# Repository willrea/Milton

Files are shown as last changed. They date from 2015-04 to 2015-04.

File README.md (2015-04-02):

# Milton

LPC1768-based platform for high altitude balloons.

###Hardware

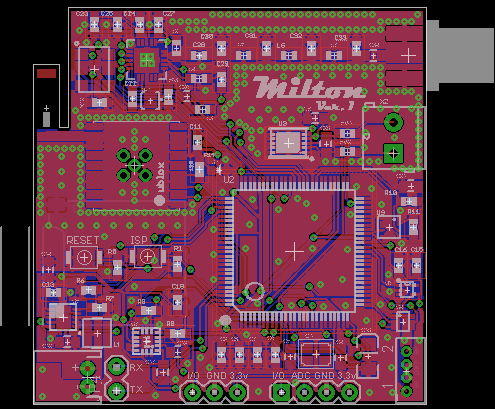
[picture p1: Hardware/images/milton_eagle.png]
Eagle


Includes:
* ublox MAX7 GPS
* Bosch BME280 Pressure/Humidity/Temperature Sensor
* Si4464 RF IC to transmit position via APRS
* Capability to trigger 2 Canon cameras loaded with CHDK
* MMA8452Q Accelerometer
* Supports a thermocouple for exterior temperature reading via a OneWire MAX31850

###Software###

*Overview of software functions*
* Beacon position and temps over APRS in a configurable amount of time
 * Add support for SI4464 RF IC
* Log raw NMEA strings to file on SD card
* Log sensor info with date/time and gps position on SD card, maybe in same file as NMEA strings? Would have to be 
compatible with GPSBabel or similar program.
* Trigger up to 2 cameras on set intervals
* Detect apogee via accelerometer triggering interrupt. Then trigger cameras and log gps at time of apogee

Hardware is licensed under a <a rel="license" href="http://creativecommons.org/licenses/by-sa/4.0/">Creative Commons Attribution-ShareAlike 4.0 International License</a>.

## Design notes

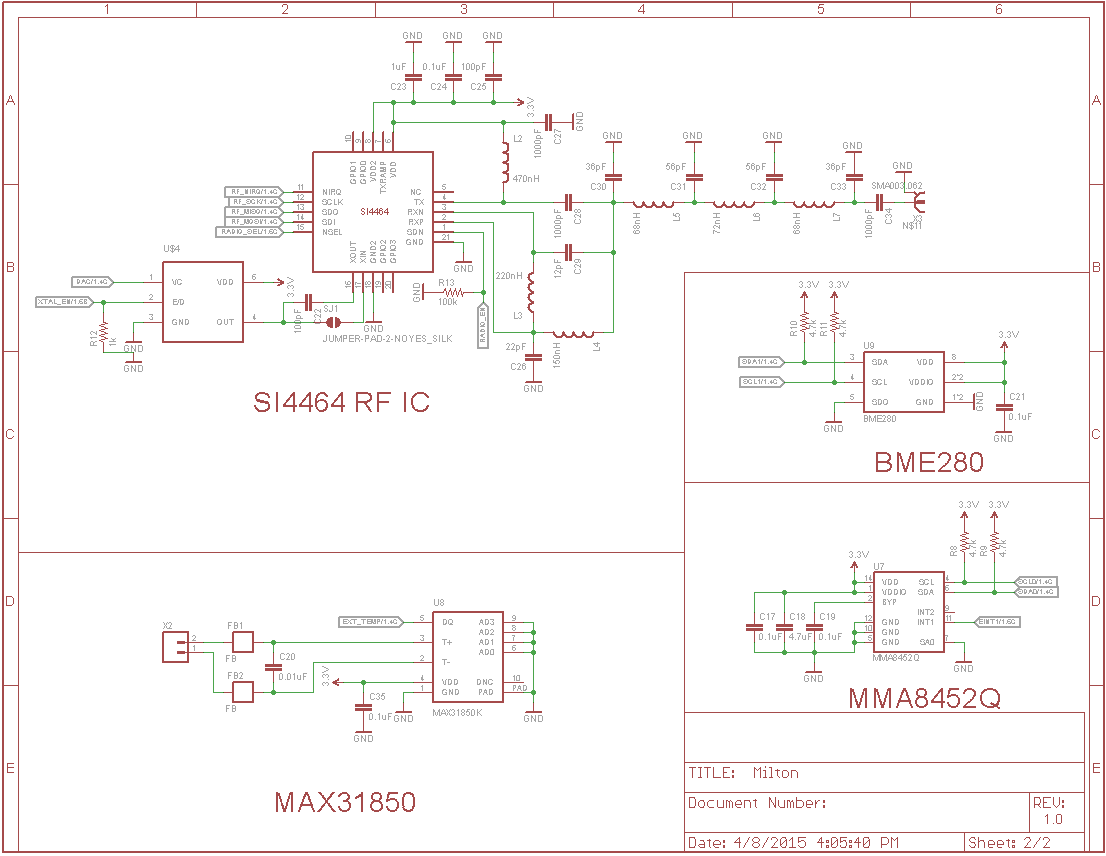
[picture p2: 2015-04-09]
Hardware/images/Schematic_P2.png

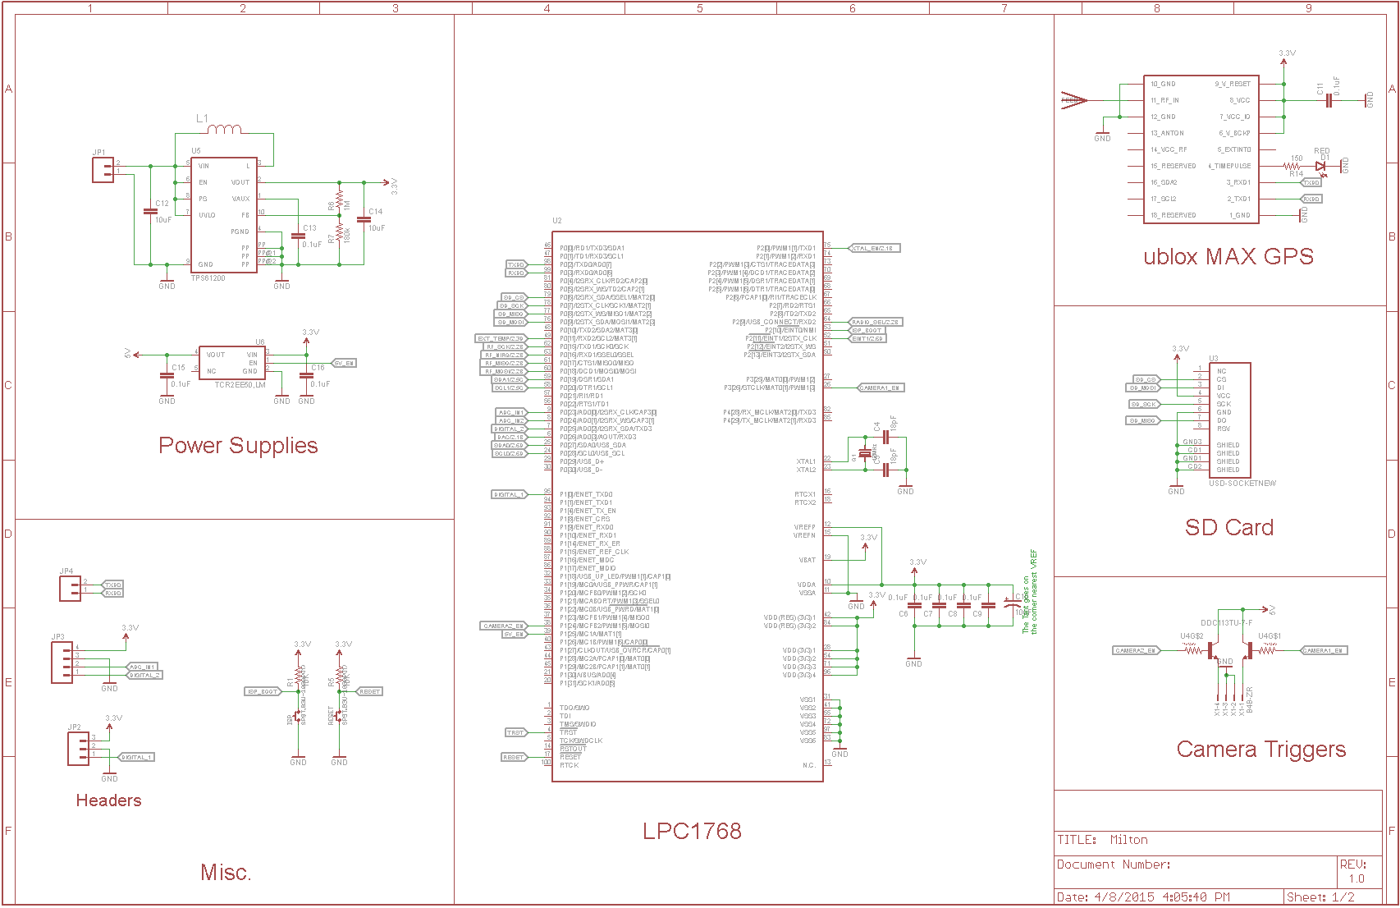
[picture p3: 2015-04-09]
Hardware/images/Schematic_P1.png

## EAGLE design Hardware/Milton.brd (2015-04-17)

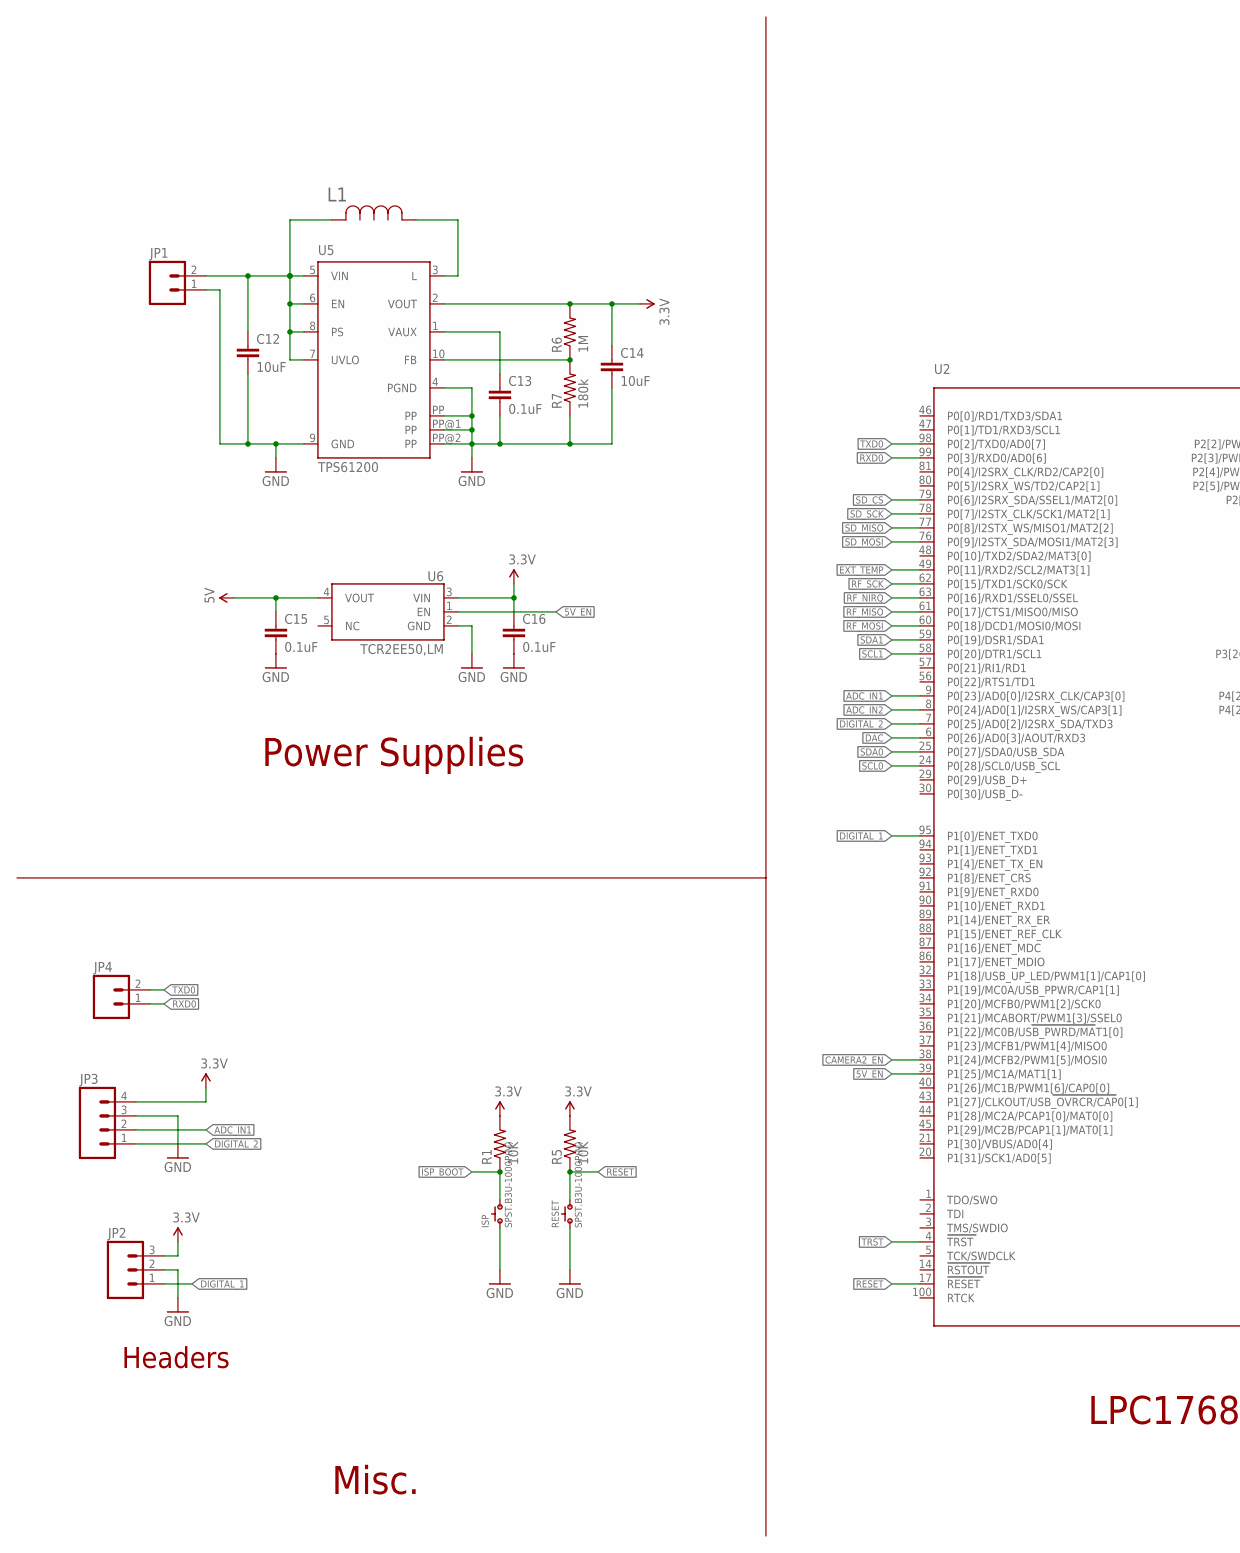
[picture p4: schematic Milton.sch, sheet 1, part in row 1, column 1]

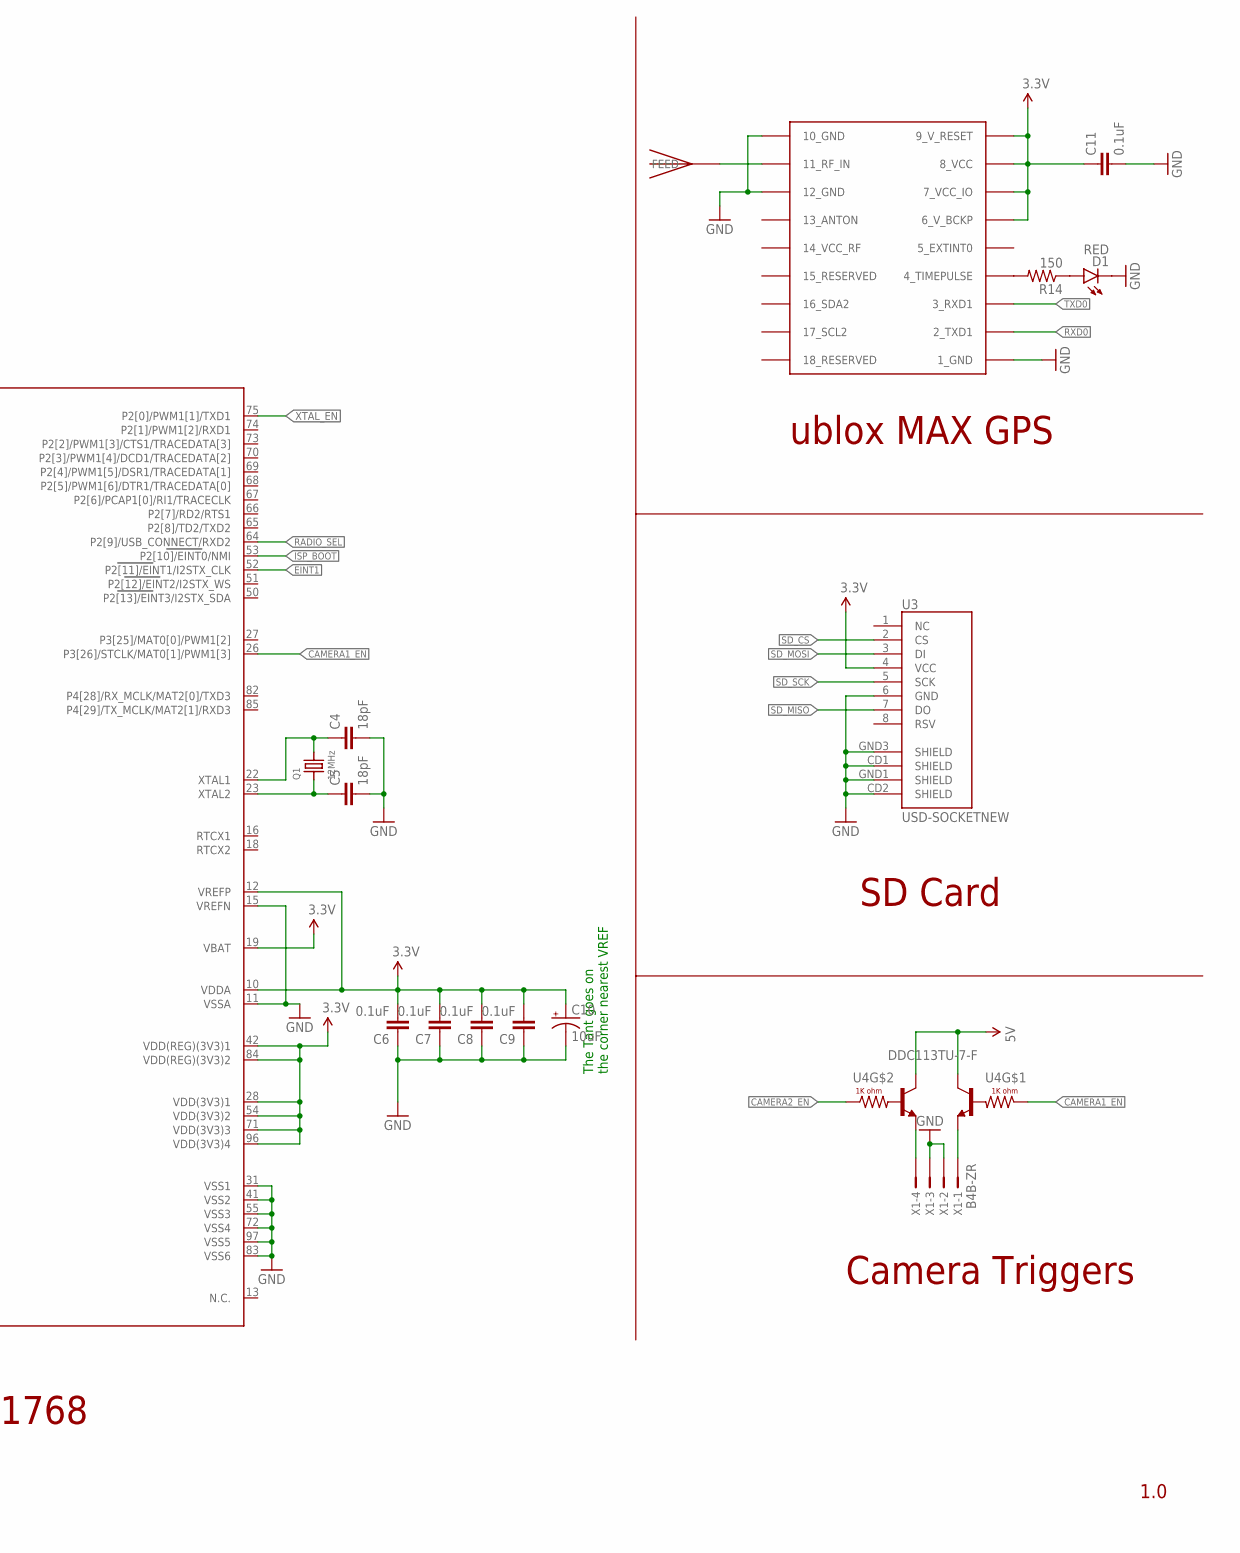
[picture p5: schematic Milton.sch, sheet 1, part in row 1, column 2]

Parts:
C4, C5: 18pF; 0805; MPN C0603C180K3GACTU
C6, C7, C8, C9, C11, C13, C15, C16: 0.1uF; 0603-CAP; MPN CL10B104KO8NNNC
C10: 10uF; EIA3216; MPN F931A106KAA
C12, C14: 10uF; 0805; MPN GRM21BR61C106KE15L
D1: RED; LED-0603; MPN LS L29K-G1J2-1-Z
ISP: SPST.B3U-1000P(M); B3U-1000P(M)
JP1: M02JST-PTH-2; JST-2-PTH; MPN S2B-PH-K-S(LF)(SN)
JP2: M03PTH; 1X03
JP3: M04PTH; 1X04
JP4: M02LOCK; 1X02_LOCK
L1: SRN3015-2R2M; IND_BOURNS_SRN3015; MPN SRN3015-4R7M
Q1: 12MHz; CRYSTAL_3.2X2.5; MPN 7V-12.000MAHE-T
R1, R5: 10K; 0603-RES; MPN ESR03EZPJ103
R6: 1M; 0603-RES; MPN MCT06030C1004FP500
R7: 180k; 0603-RES; MPN RC1608F184CS
R14: 150; 0603-RES; MPN ESR03EZPJ151
RESET: SPST.B3U-1000P(M); B3U-1000P(M)
U2: LPC1768; LQFP100; MPN LPC1768FBD100,551
U3: USD-SOCKETNEW; MICRO-SD-SOCKET-PP; MPN 101-00660-68-6
U4: DDC113TU-7-F; SC70−6; MPN DDC113TU-7-F
U5: TPS61200; S-PDSO-N10; MPN TPS61200DRCR
U6: TCR2EE50,LM; SOT50P160X60-5N
U$2: 1575AT43A40; JTI_ANTENNA-1575AT43A40; MPN 1575AT43A0040E
U$3: UBLOX_MAX; MPN MAX-7C-0
X1: B4B-ZR

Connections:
3.3V: C6.2, C7.2, C8.2, C9.2, C10.A (+), C11.1, C14.1, C16.1, JP2.3, JP3.4, R1.2, R5.2, R6.2, U2.10 (VDDA), U2.12 (VREFP), U2.19 (VBAT), U2.28 (VDD(3V3)1), U2.42 (VDD(REG)(3V3)1), U2.54 (VDD(3V3)2), U2.71 (VDD(3V3)3), U2.84 (VDD(REG)(3V3)2), U2.96 (VDD(3V3)4), U3.4 (VCC), U5.2 (VOUT), U6.3 (VIN), U$3.6_V_BCKP, U$3.7_VCC_IO, U$3.8_VCC, U$3.9_V_RESET; also elsewhere on the board
5V: C15.1, U4.3 (C), U4.6 (C), U6.4 (VOUT)
5V_EN: U2.39 (P1[25]/MC1A/MAT1[1]), U6.1 (EN)
ADC_IN1: JP3.2, U2.9 (P0[23]/AD0[0]/I2SRX_CLK/CAP3[0])
ADC_IN2: U2.8 (P0[24]/AD0[1]/I2SRX_WS/CAP3[1])
CAM1: U4.1 (E), X1.1
CAM2: U4.4 (E), X1.4
CAMERA1_EN: U2.26 (P3[26]/STCLK/MAT0[1]/PWM1[3]), U4.2 (B)
CAMERA2_EN: U2.38 (P1[24]/MCFB2/PWM1[5]/MOSI0), U4.5 (B)
DAC: U2.6 (P0[26]/AD0[3]/AOUT/RXD3); also elsewhere on the board
DIGITAL_1: JP2.1, U2.95 (P1[0]/ENET_TXD0)
DIGITAL_2: JP3.1, U2.7 (P0[25]/AD0[2]/I2SRX_SDA/TXD3)
EINT1: U2.52 (P2[11]/EINT1/I2STX_CLK); also elsewhere on the board
EXT_TEMP: U2.49 (P0[11]/RXD2/SCL2/MAT3[1]); also elsewhere on the board
GND: C4.2, C5.2, C6.1, C7.1, C8.1, C9.1, C10.C (-), C11.2, C12.2, C13.2, C14.2, C15.2, C16.2, D1.C, ISP.1, JP1.1, JP2.2, JP3.3, R7.1, RESET.1, U2.11 (VSSA), U2.15 (VREFN), U2.31 (VSS1), U2.41 (VSS2), U2.55 (VSS3), U2.72 (VSS4), U2.83 (VSS6), U2.97 (VSS5), U3.6 (GND), U3.CD1 (SHIELD), U3.CD2 (SHIELD), U3.GND1 (SHIELD), U3.GND3 (SHIELD), U5.4 (PGND), U5.9 (GND), U5.PP, U5.PP@1 (PP), U5.PP@2 (PP), U6.2 (GND), U$3.1_GND, U$3.10_GND, U$3.12_GND, X1.2, X1.3; also elsewhere on the board
IC6_RTC1: C4.1, Q1.2, U2.22 (XTAL1)
IC6_RTC2: C5.1, Q1.1, U2.23 (XTAL2)
ISP_BOOT: ISP.2, R1.1, U2.53 (P2[10]/EINT0/NMI)
unnamed: R6.1, R7.2, U5.10 (FB)
unnamed: U$2.FEED, U$3.11_RF_IN
unnamed: D1.A, R14.1
unnamed: L1.1, U5.3 (L)
unnamed: R14.2, U$3.4_TIMEPULSE
RADIO_SEL: U2.64 (P2[9]/USB_CONNECT/RXD2); also elsewhere on the board
RESET: R5.1, RESET.2, U2.17 (RESET)
RF_MISO: U2.61 (P0[17]/CTS1/MISO0/MISO); also elsewhere on the board
RF_MOSI: U2.60 (P0[18]/DCD1/MOSI0/MOSI); also elsewhere on the board
RF_NIRQ: U2.63 (P0[16]/RXD1/SSEL0/SSEL); also elsewhere on the board
RF_SCK: U2.62 (P0[15]/TXD1/SCK0/SCK); also elsewhere on the board
RXD0: JP4.1, U2.99 (P0[3]/RXD0/AD0[6]), U$3.2_TXD1
SCL0: U2.24 (P0[28]/SCL0/USB_SCL); also elsewhere on the board
SCL1: U2.58 (P0[20]/DTR1/SCL1); also elsewhere on the board
SDA0: U2.25 (P0[27]/SDA0/USB_SDA); also elsewhere on the board
SDA1: U2.59 (P0[19]/DSR1/SDA1); also elsewhere on the board
SD_CS: U2.79 (P0[6]/I2SRX_SDA/SSEL1/MAT2[0]), U3.2 (CS)
SD_MISO: U2.77 (P0[8]/I2STX_WS/MISO1/MAT2[2]), U3.7 (DO)
SD_MOSI: U2.76 (P0[9]/I2STX_SDA/MOSI1/MAT2[3]), U3.3 (DI)
SD_SCK: U2.78 (P0[7]/I2STX_CLK/SCK1/MAT2[1]), U3.5 (SCK)
TRST: U2.4 (TRST)
TXD0: JP4.2, U2.98 (P0[2]/TXD0/AD0[7]), U$3.3_RXD1
VAUX: C13.1, U5.1 (VAUX)
VIN: C12.1, JP1.2, L1.2, U5.5 (VIN), U5.6 (EN), U5.7 (UVLO), U5.8 (PS)
XTAL_EN: U2.75 (P2[0]/PWM1[1]/TXD1); also elsewhere on the board

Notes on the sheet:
The Tant goes on the corner nearest VREF
LPC1768
ublox MAX GPS
SD Card
Camera Triggers
Power Supplies
1.0
Headers
Misc.

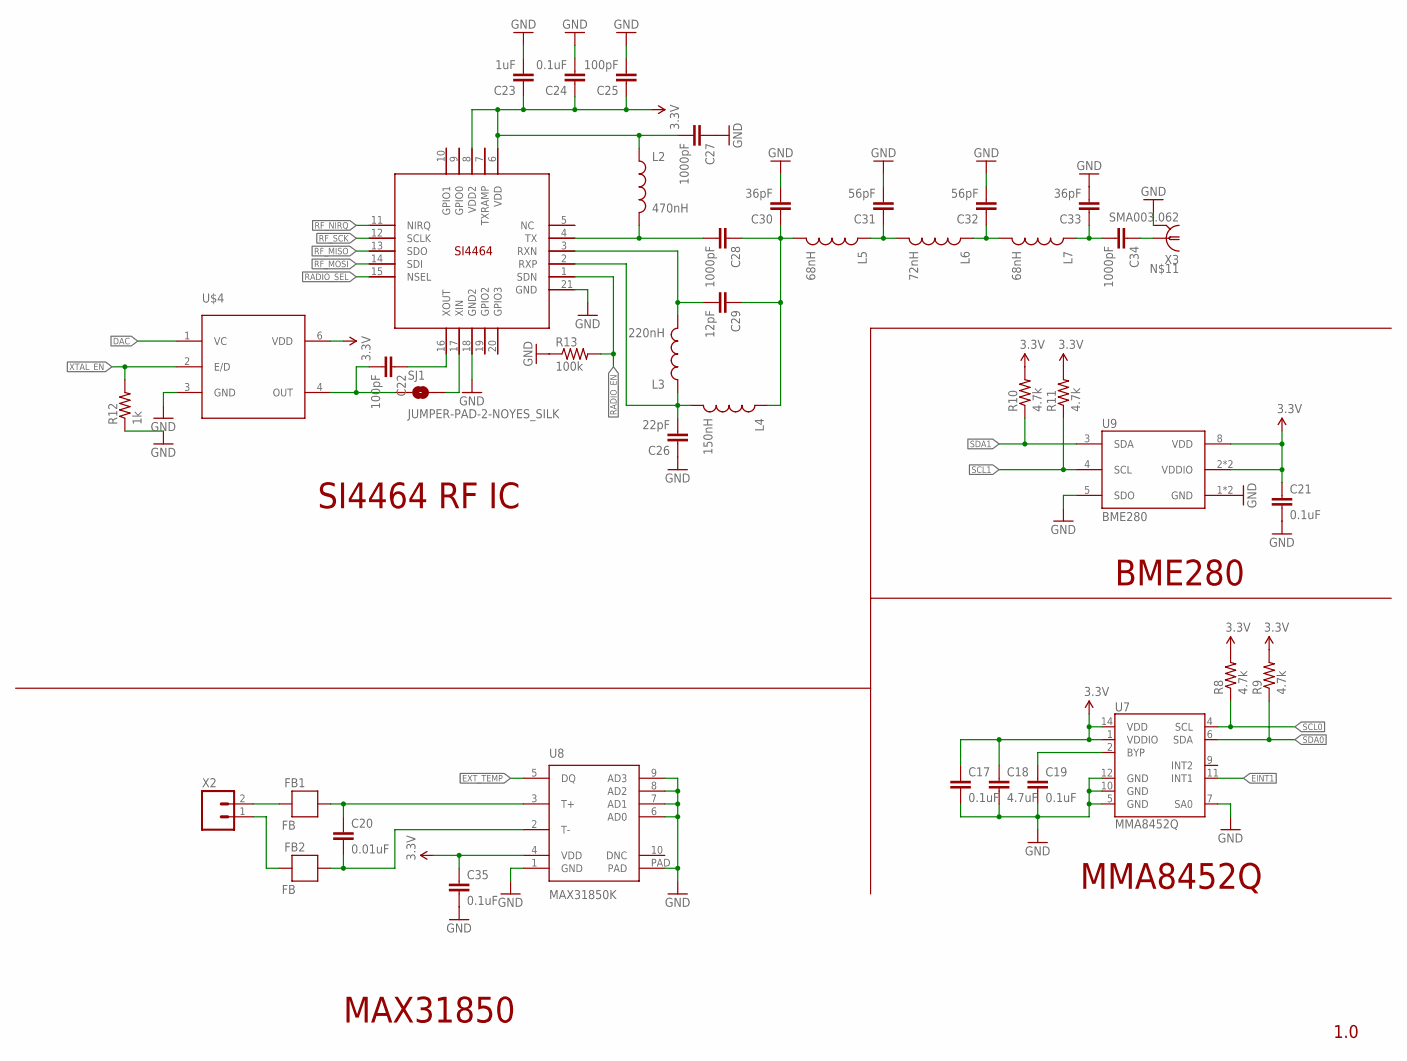
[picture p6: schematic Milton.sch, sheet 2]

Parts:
C17, C19, C21, C35: 0.1uF; 0805; MPN CL10B104KO8NNNC
C18: 4.7uF; 0603-CAP; MPN CC0603KRX5R6BB475
C20: 0.01uF; 0805; MPN C0603C103J5RACTU
C22, C25: 100pF; 0603-CAP; MPN CL10B101KB8NNNC
C23: 1uF; 0603-CAP; MPN CL10B105KP8NNNC
C24: 0.1uF; 0603-CAP; MPN CL10B104KO8NNNC
C26: 22pF; 0805; MPN C1608C0G1H220J080AA
C27, C28: 1000pF; 0603-CAP; MPN C0603C102J5RACTU
C29: 12pF; 0603-CAP; MPN CL10C120JB8NNNC
C30, C33: 36pF; 0603-CAP; MPN GRM1885C1H360JA01D
C31, C32: 56pF; 0603-CAP; MPN CL10C560JB8NNNC
C34: 1000pF; 0805; MPN C0603C102J5RACTU
FB1, FB2: FB; 0603; MPN BLM18PG471SN1D
L2: 470nH; 0603; MPN L0603CR47JRMST
L3: 220nH; 0603; MPN LQW18ANR22G00D
L4: 150nH; 0603; MPN LQW18ANR15G00D
L5, L7: 68nH; 0603; MPN LQW18AN68NG00D
L6: 72nH; 0603; MPN LQW18AN72NG00D
R8, R9, R10, R11: 4.7k; 0603-RES; MPN ERJ-3GEYJ472V
R12: 1k; 0603-RES; MPN RMCF0603JT1K00
R13: 100k; 0603-RES; MPN MCT06030C1003FP500
SJ1: JUMPER-PAD-2-NOYES_SILK; PAD-JUMPER-2-NO_YES_SILK
U7: MMA8452Q; QFN-16_0.5MM; MPN MMA8452QT
U8: MAX31850K; 10-TDFN-EP; MPN MAX31850TATB+
U9: BME280
U10: SI4464; QFN20+GNDPAD; MPN SI4464-B1B-FM
U$4: FVXO-HC53BR-27; 6-SMD; MPN FVXO-HC53BR-27
X2: M023.5MM; SCREWTERMINAL-3.5MM-2; MPN ED555/2DS
X3: SMA003.062

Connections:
3.3V: C17.1, C18.1, C21.1, C23.1, C24.1, C25.1, C27.2, C35.1, L2.1, R8.2, R9.2, R10.2, R11.2, U7.1 (VDDIO), U7.14 (VDD), U8.4 (VDD), U9.2 (VDDIO), U9.6 (VDDIO), U9.8 (VDD), U10.6 (VDD), U10.8 (VDD2), U$4.6 (VDD); also elsewhere on the board
DAC: U$4.1 (VC); also elsewhere on the board
EINT1: U7.11 (INT1); also elsewhere on the board
EXT_TEMP: U8.5 (DQ); also elsewhere on the board
GND: C17.2, C18.2, C19.2, C21.2, C23.2, C24.2, C25.2, C26.1, C27.1, C30.2, C31.2, C32.2, C33.2, C35.2, R12.1, R13.1, U7.5 (GND), U7.7 (SA0), U7.10 (GND), U7.12 (GND), U8.1 (GND), U8.6 (AD0), U8.7 (AD1), U8.8 (AD2), U8.9 (AD3), U8.PAD, U9.1 (GND), U9.5 (SDO), U9.7 (GND), U10.18 (GND2), U10.21 (GND), U$4.3 (GND), X3.C2 (2), X3.C3 (2), X3.C4 (2), X3.C5 (2); also elsewhere on the board
unnamed: C19.1, U7.2 (BYP)
unnamed: C22.1, U10.16 (XOUT)
unnamed: C32.1, L6.1, L7.2
unnamed: C28.2, L2.2, U10.4 (TX)
unnamed: C29.2, L3.2, U10.3 (RXN)
unnamed: C22.2, SJ1.1, U$4.4 (OUT)
unnamed: C26.2, L3.1, L4.2, U10.2 (RXP)
unnamed: C33.1, C34.2, L7.1
unnamed: C34.1, X3.RF (1)
unnamed: C28.1, C29.1, C30.1, L4.1, L5.2
unnamed: C31.1, L5.1, L6.2
unnamed: SJ1.2, U10.17 (XIN)
RADIO_EN: R13.2, U10.1 (SDN)
RADIO_SEL: U10.15 (NSEL); also elsewhere on the board
RF_MISO: U10.13 (SDO); also elsewhere on the board
RF_MOSI: U10.14 (SDI); also elsewhere on the board
RF_NIRQ: U10.11 (NIRQ); also elsewhere on the board
RF_SCK: U10.12 (SCLK); also elsewhere on the board
SCL0: R8.1, U7.4 (SCL); also elsewhere on the board
SCL1: R11.1, U9.4 (SCL); also elsewhere on the board
SDA0: R9.1, U7.6 (SDA); also elsewhere on the board
SDA1: R10.1, U9.3 (SDA); also elsewhere on the board
TM_FILT: C20.2, FB2.1, U8.2 (T-)
TM_RAW: FB2.2, X2.1
TP_FILT: C20.1, FB1.1, U8.3 (T+)
TP_RAW: FB1.2, X2.2
XTAL_EN: R12.2, U$4.2 (E/D); also elsewhere on the board

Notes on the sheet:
SI4464 RF IC
BME280
MMA8452Q
MAX31850
1.0

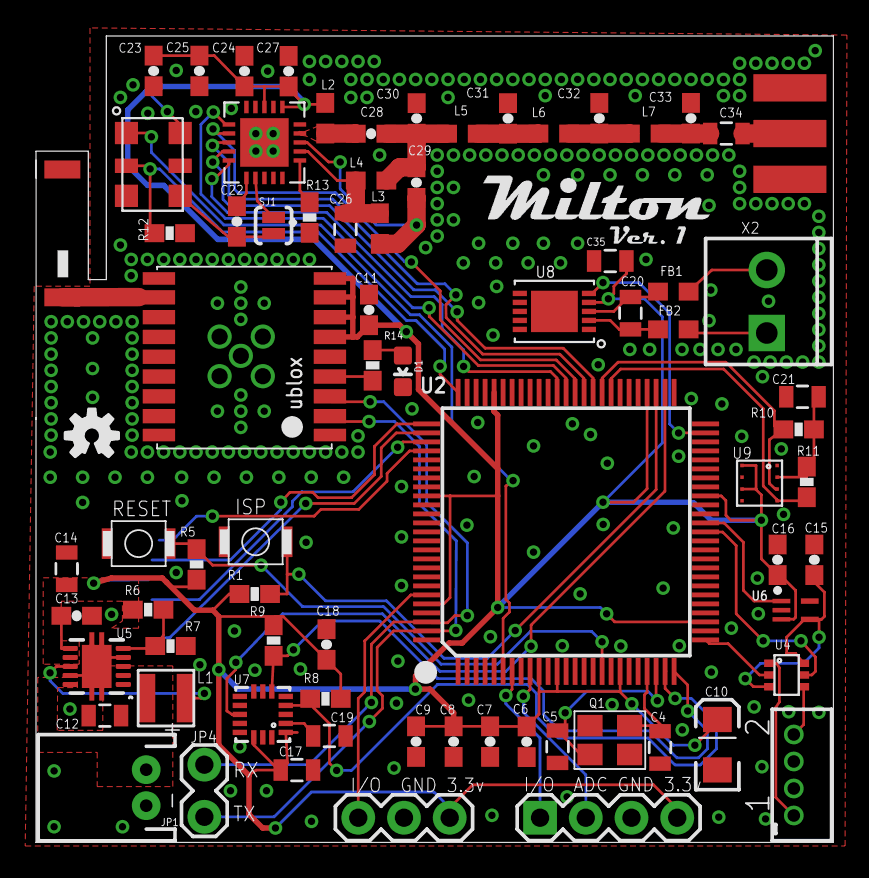
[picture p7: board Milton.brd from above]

Board: 2 copper layers, 44.3 x 44.8 mm, 77 parts (1 on the bottom side), 58 nets.

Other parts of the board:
U$1: OSHW-LOGO-S

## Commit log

2015-03-21 Initial commit.
    [Milton.brd, Milton.sch]
2015-03-25 Cleaning
    Optimize traces, add more part numbers.
    [Milton.brd, Milton.sch]
2015-03-27 Update.
    Shifted components to make room to break out another digital io
    [Milton.brd, Milton.sch]
2015-03-31 Update
    Continue cleaning up traces and adding part numbers
    [Milton.brd, Milton.sch]
2015-04-01 Cleanup
    Cleaning up layout. Optimizing traces by changing pins used.
    [Milton.brd, Milton.sch]
2015-04-01 Fix
    Forgot to connect pins 10 & 12 of ublox to GND
    [Milton.brd, Milton.sch]
2015-04-01 Change SMA connector
    [Milton.brd, Milton.sch]
2015-04-03 Cleanup schematics
    Cleanup schematics and added images
    [Milton.brd, Milton.sch]
2015-04-03 Add LED to GPS PPS output
    [Milton.brd, Milton.sch]
2015-04-09 Update
    Removed FTDI from board. Added tx/rx header and isp button
    Adjusted gps antenna position
    [Milton.brd, Milton.sch]

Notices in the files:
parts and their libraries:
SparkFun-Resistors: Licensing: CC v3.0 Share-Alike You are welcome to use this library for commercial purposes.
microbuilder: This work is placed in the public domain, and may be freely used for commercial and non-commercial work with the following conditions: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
